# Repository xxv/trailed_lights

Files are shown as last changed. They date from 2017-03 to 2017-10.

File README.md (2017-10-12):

Trailed Lights
==============

Wifi-connected jar lanterns.

This is an experiment / art project playing around with expectations. What do
you expect of a simple Ball jar lantern lining a trail in the woods at a burn?
It's likely just some cheap string lights and batteries. It may dim over time
as the batteries run out. The lights may not work at all, but hopefully someone
changed the batteries.

But what if they could interact with you?

These are Ball jar-based lanterns that are expected to last about 5 days on a
charge. They have ambient light sensors and motion detectors to help save power
and to allow interactions with people.

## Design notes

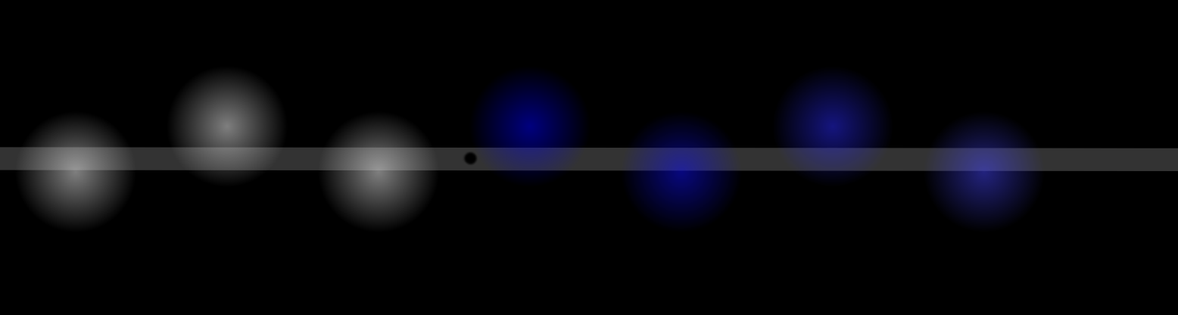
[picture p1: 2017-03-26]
proposal/colored_light_overview.png

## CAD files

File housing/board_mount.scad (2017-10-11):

diameter = 85.5;
height = 2;
lip_inset = 2;
lip_pit = 3.5;
lip_height = 1;
glass_diameter_outer = 81.5;

motion_detector_diameter = 23.3;
motion_detector_lens_clearance = 1;
motion_detector_bottom_h = 5;
motion_detector_pcb = [25.5, 35.7, 1.2];
motion_detector_pcb_parts = [25, 35, 3];

motion_detector_bracket_w=5;
motion_detector_bracket_hole=1;

battery = [34, 52, 10];
battery_z  = motion_detector_bottom_h + motion_detector_pcb[2] + motion_detector_pcb_parts[2] + 1;

feather = [23, 50, 12];
feather_bracket_w = 4;
feather_bracket_bottom_h = battery_z + battery[2] + 1;
feather_bracket_hole = 1;
feather_bracket_hole_from_edge_a = 2.5;
feather_bracket_hole_from_edge_b = 2.1;

photo_sensor_rotation = [0, 0, 0];
photo_sensor_offset = [0, feather[1]/2, 0];
photo_sensor_r = 5/2;
photo_sensor_h = 2;
photo_sensor_cut = 0.5;
photo_sensor_lead_h = 24;
photo_sensor_lead_hole_r = 0.25;

$fn = 120;
smidge = 0.01;

//mockup();

// Set up for printing
rotate([180,0,0])
  lid();

////////////////////////////////////////////////////////////

module lid() {
  radius = diameter/2;

  difference() {
    union() {
      cylinder(r=radius, h=height);

    // motion sensor bracket
    motion_detector_bracket_offset = motion_detector_diameter/2 + motion_detector_lens_clearance;
    for(r = [0 : 180 : 180])
      rotate([0, 0, r]) {
        translate([-motion_detector_pcb[0]/2, motion_detector_bracket_offset, -motion_detector_bottom_h])
          motion_detector_bracket();
        // Feather bracket
        translate([-feather[0]/2, -feather[1]/2, -feather_bracket_bottom_h]) {
          if (r == 0) {
            feather_bracket(feather_bracket_hole_from_edge_a);
          } else {
            feather_bracket(feather_bracket_hole_from_edge_b);
          }
        }
        // joiner between parts for support
        translate([-feather[0]/2, motion_detector_bracket_offset + motion_detector_bracket_w, -motion_detector_bottom_h])
          cube([feather[0], feather[1]/2 - motion_detector_bracket_offset - motion_detector_bracket_w, motion_detector_bottom_h]);
      }
    }

    // lip inset
    translate([0, 0, -lip_height])
      difference() {
        cylinder(r=radius - lip_inset, h=height);
        translate([0,0,-smidge])
          cylinder(r=radius - lip_inset - lip_pit, h=height+smidge*2);
      }

    // motion detector hole
    translate([0,0,-smidge])
      cylinder(r=motion_detector_diameter/2, h=height+smidge*2);

    // photo sensor hole
    translate(photo_sensor_offset - [0, 0, -0.5])
      rotate(photo_sensor_rotation) {
        cut_cylinder(r=photo_sensor_r + 0.25, h=height + smidge*2, cut = photo_sensor_cut);
        translate([0, 0, smidge])
        photo_resistor();

        translate([0, 0, -feather_bracket_bottom_h-0.5-smidge])
        cylinder(r=photo_sensor_r, h=feather_bracket_bottom_h+smidge);
      }
  }
}

module feather_bracket(feather_bracket_hole_from_edge) {
    difference() {
      cube([feather[0], feather_bracket_w, feather_bracket_bottom_h ]);
      translate([feather_bracket_hole_from_edge, feather_bracket_w/2, -smidge])
        cylinder(r=feather_bracket_hole, h=feather_bracket_bottom_h - 2);
      translate([feather[0]-feather_bracket_hole_from_edge, feather_bracket_w/2, -smidge])
        cylinder(r=feather_bracket_hole, h=feather_bracket_bottom_h - 2);
    }

}

module motion_detector_bracket() {
  difference() {
    cube([motion_detector_pcb[0], motion_detector_bracket_w, motion_detector_bottom_h]);
    translate([motion_detector_pcb[0]/2, motion_detector_bracket_w/2, -smidge])
      cylinder(r=motion_detector_bracket_hole, h=motion_detector_bottom_h - 2);
  }
}

module mockup() {
  lid();
  color("red")
    motion_detector();
  color("green")
  translate(photo_sensor_offset + [0, 0, 0.5])
    rotate(photo_sensor_rotation)
      photo_resistor();

  // board
  color("blue")
    translate([-feather[0]/2, -feather[1]/2, -feather_bracket_bottom_h-feather[2]])
    feather();

  // battery
  color("orange")
    rotate([0, 0, 90])
      translate([-battery[0]/2, -battery[1]/2, -battery_z-battery[2]])
        battery();

  // glass
  % translate([0, 0, -121])
  difference() {
    cylinder(r=glass_diameter_outer/2, h=121);
    translate([0, 0, 2])
      cylinder(r=glass_diameter_outer/2-lip_pit, h=121-2);
  }
}

module motion_detector() {
  difference() {
    sphere(r=motion_detector_diameter/2);
    translate([-motion_detector_diameter/2, -motion_detector_diameter/2, -motion_detector_diameter])
      cube([motion_detector_diameter,
            motion_detector_diameter,
            motion_detector_diameter]);
  }
  translate([-motion_detector_diameter/2, -motion_detector_diameter/2, -5])
    cube([motion_detector_diameter,
          motion_detector_diameter,
          5]);
  // PCB
  translate([0, 0, -motion_detector_bottom_h - motion_detector_pcb[2]]) {
    translate([-motion_detector_pcb[0]/2, -motion_detector_pcb[1]/2, 0])
      difference() {
        cube(motion_detector_pcb);
        translate([motion_detector_pcb[0]/2, 3, -smidge])
          cylinder(r=1.5, h=motion_detector_pcb[2]+smidge*2);
        translate([motion_detector_pcb[0]/2, motion_detector_pcb[1] -3, -smidge])
          cylinder(r=1.5, h=motion_detector_pcb[2]+smidge*2);
      }
      translate([-motion_detector_pcb_parts[0]/2, -motion_detector_pcb_parts[1]/2, -motion_detector_pcb_parts[2]])
        cube(motion_detector_pcb_parts);
    }
}

module feather() {
  cube(feather);
}

module battery() {
  cube(battery);
}

module cut_cylinder(r, h, cut) {
  intersection() {
    cylinder(r=r, h=h);
    translate([-r, -r + cut, 0])
    cube([r * 2, r * 2 - cut * 2, h+smidge*2]);
  }
}

module photo_resistor() {
  height = 2;
  cut_cylinder(r=photo_sensor_r, h=photo_sensor_h, cut=photo_sensor_cut);
  translate([-2.7/2, 0, -photo_sensor_lead_h])
  cylinder(r=photo_sensor_lead_hole_r, h=photo_sensor_lead_h);
  translate([2.7/2, 0, -photo_sensor_lead_h])
  cylinder(r=photo_sensor_lead_hole_r, h=photo_sensor_lead_h);
  }

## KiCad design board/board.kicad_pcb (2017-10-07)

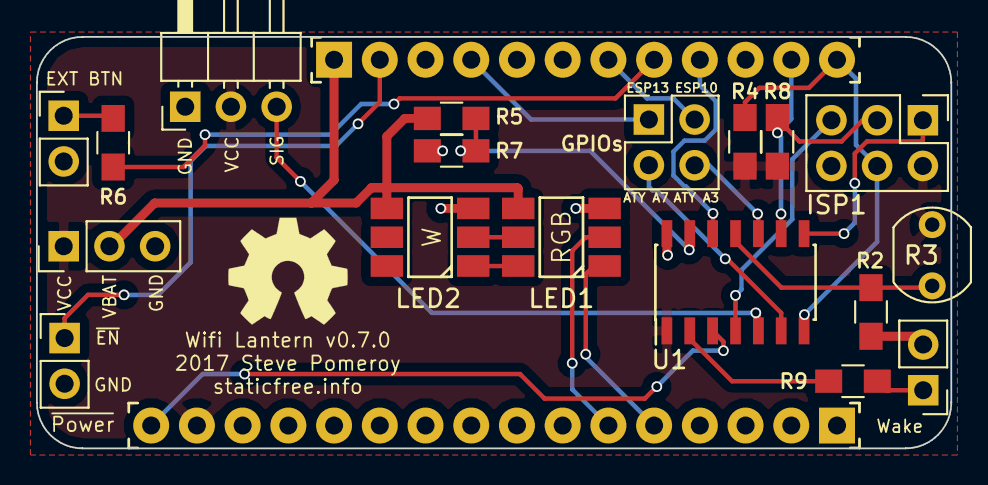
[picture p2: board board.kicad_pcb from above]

Board: 2 copper layers, 50.8 x 22.9 mm, 20 parts (0 on the bottom side), 25 nets.

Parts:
ISP1: AVR-ISP-6; Pin_Header_Straight_2x03_Pitch2.54mm
J1: MOTION DETECTOR; Pin_Header_Angled_1x03_Pitch2.54mm
J2: EXT BUTTON; Pin_Header_Straight_1x02_Pitch2.54mm
J3: EXT WAKE; Pin_Header_Straight_1x02_Pitch2.54mm
J4: ~POWER; Pin_Header_Straight_1x02_Pitch2.54mm
J5: GPWR; Pin_Header_Straight_1x03_Pitch2.54mm
J6: GPIOs; Pin_Header_Straight_2x02_Pitch2.54mm
JP1: PinHeader_01x16_2.54mm; Conn_PinHeader_1x16
JP3: PinHeader_01x12_2.54mm; Conn_PinHeader_1x12
LED1: APA102 (RGB); APA102_hand_solder
LED2: APA102 (W); APA102_hand_solder
R2: 10K; R_0805_HandSoldering
R3: R_PHOTO; Resistor_LDR_5.1x4.3_RM3.4
R4, R8: 4.7K; R_0805_HandSoldering
R5: 12K; R_0805_HandSoldering
R6, R9: 1K; R_0805_HandSoldering
R7: 30K; R_0805_HandSoldering
U1: ATTINY841-SSU; SOIC-14_3.9x8.7mm_Pitch1.27mm

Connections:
/AMBIENT: R2.1, R3.2, U1.11
/ATY_MISO: ISP1.1, U1.8
/ATY_MOSI: ISP1.4, JP3.12, R4.2, U1.7
/ATY_PA3: J6.4, U1.10
/ATY_PA7: J6.3, U1.6
/ATY_SCK: ISP1.3, JP3.11, R8.2, U1.9
/BAT_MON: R5.2, R7.1, U1.13
/D6: JP3.9, U1.12
/D9: JP3.8, R6.2
/D10: J6.2, JP3.7
/D13: J6.1, JP3.4
/EN: J4.1, JP3.2
/EXT_WAKE: R9.2, U1.2
/MOSI: JP1.5, LED1.1
/MOTION_SIG: J1.3, U1.5
/SCK: JP1.6, LED1.2
/VBAT: J5.2, JP3.1, LED1.4, LED2.4, R5.1
/~ATY_RST: ISP1.5, U1.4
/~RESET: JP1.16, U1.3
GND: ISP1.6, J1.1, J2.2, J3.2, J4.2, J5.3, JP1.13, LED1.3, LED2.3, R2.2, R7.2, U1.14
unnamed: J2.1, R6.1
unnamed: J3.1, R9.1
unnamed: LED1.5, LED2.2
unnamed: LED1.6, LED2.1
VCC: ISP1.2, J1.2, J5.1, JP1.15, R3.1, R4.1, R8.1, U1.1

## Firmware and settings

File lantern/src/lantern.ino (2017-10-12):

#include "Secrets.h"

#include <Arduino.h>
#include <ESP8266WiFi.h>
#include <DNSServer.h>
#include <ESP8266WebServer.h>
#include <WiFiManager.h>
#define FASTLED_ESP8266_RAW_PIN_ORDER
#include <FastLED.h>
#include <Ticker.h>
#include <PubSubClient.h>
#include <Wire.h>

enum DeviceMode {
  booting = 0,
  normal,
  wifi_setup
};

const static byte POWER_MANAGER_ADDR    = 0x50;
const static byte REG_GET_BATTERY_LEVEL = 0x01;
const static byte REG_GET_AMBIENT_LEVEL = 0x02;
const static byte REG_GET_MOTION        = 0x03;
const static byte REG_SET_ESP_ASLEEP    = 0x04;

const static uint8_t STATUS_LED = 0;
// APA102 LEDs
const static uint8_t NUM_LEDS = 2;

// the number of seconds of no motion until lantern sleeps
const static uint8_t DEFAULT_MOTION_TIMEOUT_S = 15;
const static uint8_t POWERDOWN_BATTERY_LEVEL = 10;
const static int AMBIENT_LIGHT_OFF_LEVEL = 90;

const static byte RTC_FINGERPRINT[] = { 'l', 'n' };

WiFiManager wifiManager;
Ticker animationTicker;

#ifdef LANTERN_USE_SSL
WiFiClientSecure wifi;
#else
WiFiClient wifi;
#endif

PubSubClient client(wifi);

CRGB leds[NUM_LEDS];
CRGB prev_leds[NUM_LEDS];
CRGB next_leds[NUM_LEDS];
CRGB default_leds[NUM_LEDS];

fract8 color_fade = 0;

uint8_t mac[WL_MAC_ADDR_LENGTH];
char device_id[9];
char lantern_id[18];
char lantern_id_all[20];
char lantern_id_motion[24];
char lantern_id_status[24];
char lantern_id_sensors[25];

// MQTT-Configurable parameters
int motion_timeout_s = DEFAULT_MOTION_TIMEOUT_S;
bool default_color_on_sleep = 0;

// Transient state
uint8_t ambient = 0;
uint8_t battery = 0;
bool is_motion = false;
int no_motion_since_s = 0;
int ambient_bright_since_s = 0;
bool is_fading_off_to_sleep = 0;

byte rtc_state[sizeof(RTC_FINGERPRINT) + NUM_LEDS * 3];

DeviceMode device_mode = booting;

void configModeCallback(WiFiManager *myWiFiManager) {
  device_mode = wifi_setup;
  leds[0] = CRGB::Yellow;
  leds[0].nscale8(127);

  FastLED.show();
}

/**
 * Set the given power manager register to the supplied value.
 */
bool setPMRegister(uint8_t reg, uint8_t value) {
  uint8_t buff[2];

  Wire.beginTransmission(POWER_MANAGER_ADDR);
  buff[0] = reg;
  buff[1] = value;
  Wire.write(buff, 2);
  int result = Wire.endTransmission();

  if (result) {
    Serial.print("Error setting register: ");
    Serial.println(result);

    return false;
  }

  return value;
}

/**
 * Retrieve the given power manager register value.
 */
uint8_t getPMRegister(uint8_t reg) {
  Wire.beginTransmission(POWER_MANAGER_ADDR);
  Wire.write(reg);
  int result = Wire.endTransmission();

  if (result) {
    Serial.print("Error requesting register: ");
    Serial.println(result);

    return 0;
  }

  uint8_t gotBytes = Wire.requestFrom(POWER_MANAGER_ADDR, (uint8_t)1);
  uint8_t value;

  while(Wire.available()) {
    value = Wire.read();
  }

  Wire.endTransmission();

  return value;
}

uint8_t getAmbient() {
  return getPMRegister(REG_GET_AMBIENT_LEVEL);
}

uint8_t getBattery() {
  return getPMRegister(REG_GET_BATTERY_LEVEL);
}

bool getMotion() {
  return getPMRegister(REG_GET_MOTION);
}

void saveLedState() {
  memcpy(rtc_state, RTC_FINGERPRINT, sizeof(RTC_FINGERPRINT));

  for (uint8_t i = 0; i < NUM_LEDS; i++) {
    memcpy(&rtc_state[sizeof(RTC_FINGERPRINT) + i * 3], leds[i].raw, 3);
  }

  if (!system_rtc_mem_write(70, rtc_state, sizeof(rtc_state))) {
    Serial.println("Could not write LED state to RTC");
  }
}

void restoreLedsFromState(CRGB* arr) {
  for (uint8_t i = 0; i < NUM_LEDS; i++) {
    memcpy(arr[i].raw, &rtc_state[sizeof(RTC_FINGERPRINT) + i * 3], 3);
  }
}

void restoreLedState() {
  if (!system_rtc_mem_read(70, rtc_state, sizeof(rtc_state))) {
    Serial.println("Could not read LED state from RTC");
    return;
  }

  if (memcmp(rtc_state, RTC_FINGERPRINT, sizeof(RTC_FINGERPRINT)) != 0) {
    Serial.println("RTC memory does not contain fingerprint. Not restoring");
    return;
  }

  restoreLedsFromState(leds);
  restoreLedsFromState(next_leds);
  restoreLedsFromState(prev_leds);
}

void snapshotLeds() {
    prev_leds[0] = leds[0];
    prev_leds[1] = leds[1];
    color_fade = 0;
}

void powerDown() {
  Serial.println("Powering down");
  FastLED.clear(true);
  beginSleep(0);
}

void gentleSleep() {
  if (default_color_on_sleep) {
    snapshotLeds();
    next_leds[0] = default_leds[0];
    next_leds[1] = default_leds[1];
    is_fading_off_to_sleep = true;
  } else {
    beginSleep(0);
  }
}

void beginSleep(long sleepTimeMs) {
  Serial.println("Sleeping now");
  saveLedState();
  setPMRegister(REG_SET_ESP_ASLEEP, true);
  ESP.deepSleep(sleepTimeMs * 1000);
}

void publishSensorStatus() {
    char format_str[64];
    sprintf(format_str, "{\"ambient\":%d,\"battery\":%d,\"motion\":%s}",
            ambient, battery, is_motion ? "true" : "false");
    client.publish(lantern_id_sensors, format_str);
}

long decodeColor(std::string &colorString) {
  std::string modifiedColor = colorString;
  modifiedColor.replace(0, 1, "0x");
  return strtoul(modifiedColor.c_str(), nullptr, 16);
}

void mqtt_callback(char* topic, byte* payload, unsigned int length) {
  std::string payload_str ((char *)payload, length);

  Serial.print("Got message at topic: ");
  Serial.println(topic);
  char* subpath = topic + strlen(lantern_id) + 1;

  if (strcmp("lanterns/motion_timeout", topic) == 0) {
    motion_timeout_s = strtol(payload_str.c_str(), nullptr, 10);
    Serial.printf("Setting motion timeout to: %d\n", motion_timeout_s);
  } else if (strcmp("lanterns/default_color", topic) == 0) {
    Serial.println("Setting default color");
    default_leds[0] = decodeColor(payload_str);
  } else if (strcmp("lanterns/default_white", topic) == 0) {
    Serial.println("Setting default white");
    default_leds[1] = decodeColor(payload_str);
  } else if (strcmp("lanterns/default_color_on_sleep", topic) == 0) {
    default_color_on_sleep = strtol(payload_str.c_str(), nullptr, 10);
    Serial.printf("Setting default color on sleep to: %d\n", default_color_on_sleep);
  } else if (strcmp("color", subpath) == 0) {
    snapshotLeds();
    next_leds[0] = decodeColor(payload_str);
  } else if (strcmp("white", subpath) == 0) {
    snapshotLeds();
    next_leds[1] = decodeColor(payload_str);
  } else if (strcmp("lanterns/color", topic) == 0) {
    snapshotLeds();
    next_leds[0] = decodeColor(payload_str);
  } else if (strcmp("lanterns/white", topic) == 0) {
    snapshotLeds();
    next_leds[1] = decodeColor(payload_str);
  } else if (strcmp("sleep", subpath) == 0) {
    long sleepTimeMs = strtoul(payload_str.c_str(), nullptr, 10);
    beginSleep(sleepTimeMs);
  } else if (strcmp("status_query", subpath) == 0) {
    publishSensorStatus();
  }
}

void setup() {
  Serial.begin(115200);
  Wire.begin();
  Wire.setClockStretchLimit(100000);
  pinMode(STATUS_LED, OUTPUT);
  digitalWrite(STATUS_LED, 1); // LED off

  FastLED.addLeds<APA102, MOSI, SCK, BGR>(leds, NUM_LEDS);
  FastLED.setDither(0);

  wifiManager.setAPCallback(configModeCallback);

  if (!wifiManager.autoConnect("Lantern")) {
    ESP.reset();
    delay(1000);
  }

  if (device_mode == wifi_setup) {
    device_mode = normal;
    FastLED.showColor(CRGB::Black);
  }

  restoreLedState();

  WiFi.macAddress(mac);
  sprintf(device_id, "%02x%02x%02x%02x", mac[2], mac[3], mac[4], mac[5]);
  sprintf(lantern_id, "lantern/%s", device_id);
  sprintf(lantern_id_all, "lantern/%s/#", device_id);
  sprintf(lantern_id_motion, "lantern/%s/motion", device_id);
  sprintf(lantern_id_status, "lantern/%s/status", device_id);
  sprintf(lantern_id_sensors, "lantern/%s/sensors", device_id);

  randomSeed(micros());

  client.setServer(mqtt_host, mqtt_port);
  client.setCallback(mqtt_callback);
}

void reconnect() {
  // Loop until we're reconnected
  while (!client.connected()) {
    // Create a random client ID
    String clientId = "lantern-";
    clientId += device_id;

    bool connected;
    if (strlen(mqtt_user) == 0) {
      connected = client.connect(clientId.c_str(), lantern_id_status,
                                 0, 1, "offline");
    } else {
      connected = client.connect(clientId.c_str(), mqtt_user, mqtt_password,
                                 lantern_id_status, 0, 1, "offline");
    }

    if (connected) {
      digitalWrite(STATUS_LED, 1);
      // Once connected, publish an announcement...
      client.subscribe(lantern_id_all);
      client.subscribe("lanterns/#");

      client.publish(lantern_id_status, "online", 1);
      client.publish(lantern_id_motion, "");
    } else {
      digitalWrite(STATUS_LED, 0);
    }
  }
}

void loop() {
  while (!client.connected()) {
    reconnect();
  }

  client.loop();

  EVERY_N_MILLIS(5) {
    if (color_fade < 0xff) {
      color_fade += 1;

      for (uint8_t i = 0; i < NUM_LEDS; i++) {
        leds[i] = prev_leds[i].lerp8(next_leds[i], color_fade);
      }

      // Do this once the color has settled in case there's a stray board reset
      if (color_fade == 0xff) {
        saveLedState();
      }

      FastLED.show();
    }
  }

  EVERY_N_SECONDS(1) {
    ambient = getAmbient();
    battery = getBattery();
    is_motion = getMotion();
    Serial.printf("Ambient: %d, battery: %d, motion: %d\n", ambient, battery, is_motion);

    if (is_motion) {
      no_motion_since_s = 0;
    } else {
      no_motion_since_s++;
    }

    if (ambient >= AMBIENT_LIGHT_OFF_LEVEL) {
      ambient_bright_since_s++;
    } else {
      ambient_bright_since_s = 0;
    }

    Serial.print("No motion since: ");
    Serial.println(no_motion_since_s);

    if (battery < POWERDOWN_BATTERY_LEVEL) {
      powerDown();
    }
  }

  EVERY_N_SECONDS(5) {
    publishSensorStatus();
  }

  if (is_fading_off_to_sleep) {
    if (color_fade == 0xff) {
      is_fading_off_to_sleep = 0;
      beginSleep(0);
    }
  } else if (no_motion_since_s >= motion_timeout_s) {
    if (ambient_bright_since_s < 10) {
      gentleSleep();
    } else {
      Serial.println("It's too bright.");
      powerDown();
    }
  }
}

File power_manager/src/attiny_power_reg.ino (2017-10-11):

#include <avr/sleep.h>
#include <WireS.h>

// Pin mapping (Arduino pin numbers)
const static byte BAT_MON_PIN   = A0;
const static byte AMBIENT_PIN   = A2;
const static byte ESP_RESET_PIN = PIN_B1;
const static byte ESP_RTC_PIN   = PIN_A1;
const static byte EXT_WAKE_PIN  = PIN_B0;
const static byte MOTION_PIN    = PIN_B2;

const static byte MY_I2C_ADDR           = 0x50;
const static byte REG_GET_BATTERY_LEVEL = 0x01;
const static byte REG_GET_AMBIENT_LEVEL = 0x02;
const static byte REG_GET_MOTION        = 0x03;
const static byte REG_SET_ESP_ASLEEP    = 0x04;

// timings
// the amount of time the reset pin is held low
const static byte RESET_TIME_MS  = 100;
const static byte DEBOUNCE_TIME_MS = 50;

const static byte CMD_GET_BATT   = 0x62;
const static byte CMD_SET_RTC_EN = 0x72;
const static byte CMD_SLEEP_NOW  = 0x7A;

// Calibrations
const static int BATTERY_VAL_LOW  = 312;
const static int BATTERY_VAL_HIGH = 370;
const static int BATTERY_LEVEL_CRITICAL = 10;

// Brighter than this and it won't wake the ESP
const static int AMBIENT_VAL_BRIGHT = 100;
const static int AMBIENT_VAL_DARK   = 50;

static bool wake_on_rtc = true;
static bool wake_on_motion = true;
static bool wake_on_external = true;

bool is_dark = true;
bool is_esp_sleeping = false;
uint8_t last_motion = 0xff;
uint8_t last_ext_wake = 0xff;
uint8_t last_esp_reset = 0xff;
volatile uint8_t current_register = 0;

volatile bool triggered = false;
volatile unsigned long triggered_time = 0;

volatile uint8_t battery;
volatile int ambient;

ISR(PCINT0_vect) {
  triggered = true;
  triggered_time = millis();
}

ISR(PCINT1_vect) {
  triggered = true;
  triggered_time = millis();
}

/**
 * Enable Pin Change Interrupt on given pin number.
 */
void pciSetup(byte pin) {
  bitSet(*digitalPinToPCMSK(pin), digitalPinToPCMSKbit(pin)); // enable pin
  bitSet(*digitalPinToPCICR(pin), digitalPinToPCICRbit(pin)); // enable interrupt
}

/**
 * Enable sleep mode and turn on pin change interrupt
 */
void sleepNow() {
  set_sleep_mode(SLEEP_MODE_PWR_DOWN);
  sleep_enable();

  // -.- zzz...
  sleep_mode();

  // !! O.O
  sleep_disable();

  disable_interrupts();
}

void enable_interrupts() {
  // Enable PC interrupt
  if (wake_on_motion) {
    pciSetup(MOTION_PIN);
  }

  if (wake_on_external) {
    pciSetup(EXT_WAKE_PIN);
    pinMode(EXT_WAKE_PIN, INPUT_PULLUP);
  }

  if (wake_on_rtc) {
    pciSetup(ESP_RTC_PIN);
  }
}

void disable_interrupts() {
  // Disable PC interrupt
  if (wake_on_motion) {
    bitClear(*digitalPinToPCICR(MOTION_PIN),
              digitalPinToPCICRbit(MOTION_PIN));
  }

  if (wake_on_external) {
    bitClear(*digitalPinToPCICR(EXT_WAKE_PIN),
              digitalPinToPCICRbit(EXT_WAKE_PIN));
  }

  if (wake_on_rtc) {
    bitClear(*digitalPinToPCICR(ESP_RTC_PIN),
              digitalPinToPCICRbit(ESP_RTC_PIN));
  }
}

int getAmbient() {
  return analogRead(AMBIENT_PIN);
}

uint8_t scaleAnalogReadToByte(int read) {
  return map(read, 0, 1023, 0, 255);
}

uint8_t getBattery() {
  return constrain(map(analogRead(BAT_MON_PIN),
                       BATTERY_VAL_LOW, BATTERY_VAL_HIGH, 0, 100),
                   0, 100);
}

void onReceive(size_t num_bytes) {
  if (num_bytes == 0) {
    return;
  }

  current_register = Wire.read();

  switch (current_register) {
    case REG_SET_ESP_ASLEEP:
      if (Wire.available()) {
        is_esp_sleeping = Wire.read();
      }
    break;

    default:
      while (Wire.available()) {
        Wire.read();
      }
  }
}

void onRequest() {
  if (current_register == REG_GET_BATTERY_LEVEL) {
    Wire.write(battery);
  } else if (current_register == REG_GET_AMBIENT_LEVEL) {
    Wire.write(scaleAnalogReadToByte(ambient));
  } else if (current_register == REG_GET_MOTION) {
    Wire.write(!last_motion);
  }

  current_register = 0;
}

void wake_esp() {
  digitalWrite(ESP_RESET_PIN, LOW);
  delay(RESET_TIME_MS);
  digitalWrite(ESP_RESET_PIN, HIGH);
  is_esp_sleeping = false;
}

void setup() {
  pinMode(ESP_RESET_PIN, OUTPUT);
  pinMode(AMBIENT_PIN, INPUT);
  pinMode(BAT_MON_PIN, INPUT);

  pinMode(MOTION_PIN, INPUT);
  pinMode(EXT_WAKE_PIN, INPUT);
  pinMode(ESP_RTC_PIN, INPUT);

  Wire.begin(MY_I2C_ADDR);
  Wire.onReceive(onReceive);
  Wire.onRequest(onRequest);

  // Reset output is active low
  digitalWrite(ESP_RESET_PIN, HIGH);

  enable_interrupts();
}

void loop() {
  battery = getBattery();
  ambient = getAmbient();

  if (is_dark && ambient >= AMBIENT_VAL_BRIGHT) {
    is_dark = false;
  } else if (!is_dark && ambient <= AMBIENT_VAL_DARK) {
    is_dark = true;
  }

  if (triggered && (millis() - triggered_time) > DEBOUNCE_TIME_MS) {
    // only handle trigger on risen edge
    uint8_t motion_val = !digitalRead(MOTION_PIN);
    uint8_t ext_wake_val = digitalRead(EXT_WAKE_PIN);
    uint8_t esp_reset_val = digitalRead(ESP_RESET_PIN);

    if (is_dark &&
        is_esp_sleeping &&
        battery > BATTERY_LEVEL_CRITICAL &&
        ((motion_val != last_motion && last_motion)
          || (ext_wake_val  != last_ext_wake  && ext_wake_val)
          || (esp_reset_val != last_esp_reset && esp_reset_val))) {
        wake_esp();
    }

    triggered = false;
    enable_interrupts();
    last_ext_wake = ext_wake_val;
    last_esp_reset = esp_reset_val;
    last_motion = motion_val;
  }

  delay(10);
}

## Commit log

2017-04-03 First pass at lantern ESP8266 device
2017-04-04 Turn off LED on pin 0
2017-04-06 Set motion pin to one not already in use; keep color after reboot
    [lantern.ino]
2017-04-12 Lantern: don't reset to black on boot
    [lantern.ino]
2017-06-22 Add housing
    [board_mount.scad]
2017-06-23 Add motion detector mounting bracket
    [board_mount.scad]
2017-07-30 Add first pass at board
    [board.kicad_pcb, board.sch]
2017-08-03 Add attiny85 to control power
    [board.kicad_pcb, board.sch]
2017-08-06 Add protection resistors
    [board.kicad_pcb, board.sch]
2017-08-07 Move ISP header further from LEDs to prevent shadows
    [board.kicad_pcb, board.sch]
2017-08-08 Move headers so they'll fit inside a jar
    [board.kicad_pcb]
2017-08-08 Move motion detector header further inward
    [board.kicad_pcb]
2017-08-09 Fix photoresistor circuit
    [board.kicad_pcb, board.sch]
2017-08-09 Move photoresistor in housing
    [board_mount.scad]
2017-08-12 Add I2C lines between between attiny and ESP8266
    [board.kicad_pcb, board.sch]
2017-08-13 Add power button and GPIO16 reset jumper
    * Remove redundant resistors
    [board.kicad_pcb, board.sch]
2017-08-13 Clean up fab layer
    [board.kicad_pcb]
2017-08-13 Add feather mounting brackets
    [board_mount.scad]
2017-08-13 Housing: add Feather bracket; room for battery
    [board_mount.scad]
2017-08-13 Tweak part hole placement
    [board_mount.scad]
2017-08-18 Board updates
    [board.kicad_pcb]
2017-08-18 Add Attinyx5-based power manager
2017-08-20 Add power breakout; updated on-board docs
    [board.kicad_pcb, board.sch]
2017-08-20 Improve on-board docs
    [board.kicad_pcb]
2017-08-20 Remove 3D model for extra power breakout
    [board.kicad_pcb]
2017-08-21 Update board to add power breakout
    [board.sch]
2017-08-22 Rework board to use Attiny84
    MOAR GPIOS!
    * Add battery level monitor
    * Move RTC signal to power controller
    * Add external wake signal breakout
    [board.kicad_pcb, board.sch]
2017-08-22 Port pin change interrupts to arduino
2017-08-26 Switch footprint part number
    [board.kicad_pcb, board.sch]
2017-09-07 Fix up power manager interrupts
    * add pull-up
    * add 50ms debounce timeout
    [attiny_power_reg.ino]
2017-09-08 Use device ID for MQTT client ID
2017-10-07 Add power manager
2017-10-07 Move motion tracking to power manager; add white LED
2017-10-07 Move to new Arduino framework; add ambient support
2017-10-07 Board revision 2
    * Only connect motion detector to power manager
    * Move ambient sensor to power manager
    * Increase spacing on LEDs; move to hand solder footprint
    [board.kicad_pcb, board.sch]
2017-10-07 Upgrade to kicad 4.0.7
    [board.kicad_pcb]
2017-10-07 Add GPIO header; move attiny further from LEDs
    [board.kicad_pcb, board.sch]
2017-10-07 Add first pass at ESP8266 I2C control
2017-10-07 Add simple crossfade animation for color setting
    * Save LED state across deep sleeps
2017-10-07 Final pass at preserving LED state across deep sleeps
2017-10-11 Update power manager to use attiny841
2017-10-11 Fix bug with ESP talking to attiny
    [lantern.ino]
2017-10-11 Calibrate battery
2017-10-11 Add two new power manager registers: motion and sleep
2017-10-11 Add RTC memory fingerprint to avoid weird colors on power up
    [lantern.ino]
2017-10-11 Move to proper "sensors" topic; cleanup
2017-10-11 Fix broken ambient logic
    [attiny_power_reg.ino]
2017-10-11 Move ADC sampling to main loop
2017-10-11 Add critical battery protection
2017-10-11 Add battery power down
2017-10-11 Default to the printed part in housing
    [board_mount.scad]
2017-10-11 Iterate housing measurements based on 3D print
    [board_mount.scad]
2017-10-11 Motion value is inverted
    [attiny_power_reg.ino]
